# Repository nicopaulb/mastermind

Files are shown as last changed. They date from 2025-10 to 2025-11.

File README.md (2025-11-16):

# Electronic mastermind

Find the followings items : 
- `src` : Embedded code for the board
- `dts` : Project specific Zephyr bindings
- `boards`: Zephyr devicetree overlays for the nRF microcontrollers
- `7seg_driver_module`: Zephyr driver for 7-segments display with 74HC595 shift register
- `flutter-app` : Flutter companion application for interacting with the Mastermind via BLE
- `pcb` : All KiCad files for PCB manufacturing and electric schema

Youtube Video (https://www.youtube.com/watch?v=6QL7J55KHXo)

Read more about it here : https://blog.beniserv.fr/posts/mastermind/

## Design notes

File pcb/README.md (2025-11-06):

# KiCad PCB files

For Kicad 9

<p>
    
    
</p>

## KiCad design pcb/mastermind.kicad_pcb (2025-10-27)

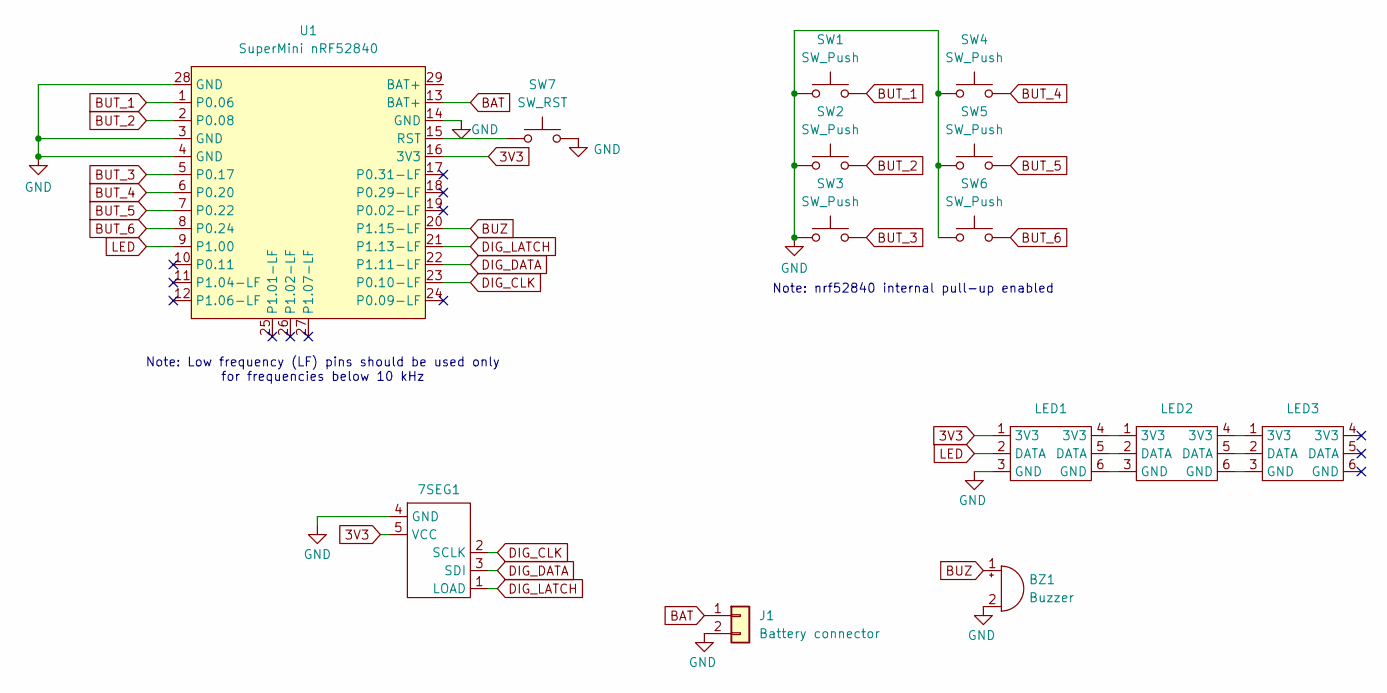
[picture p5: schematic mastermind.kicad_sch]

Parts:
7SEG1: 7seg
BZ1: Buzzer; Buzzer_12x9.5RM7.6
J1: Battery connector; JST_PH_B2B-PH-K_1x02_P2.00mm_Vertical
LED1: LED Strip 4 LED
LED2, LED3: LED Strip 2 LED
SW1, SW2, SW3, SW4, SW5, SW6: SW_Push; SW_PUSH-12mm
SW7: SW_RST; SW_PUSH-12mm
U1: SuperMini nRF52840; SuperMini NRF52840

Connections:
3V3: 7SEG1.5 (VCC), LED1.1 (3V3), U1.16 (3V3)
BAT: J1.1, U1.13 (BAT+)
BUT_1: SW1.2, U1.1 (P0.06)
BUT_2: SW2.2, U1.2 (P0.08)
BUT_3: SW3.2, U1.5 (P0.17)
BUT_4: SW4.2, U1.6 (P0.20)
BUT_5: SW5.2, U1.7 (P0.22)
BUT_6: SW6.2, U1.8 (P0.24)
BUZ: BZ1.1 (+), U1.20 (P1.15-LF)
DIG_CLK: 7SEG1.2 (SCLK), U1.23 (P0.10-LF)
DIG_DATA: 7SEG1.3 (SDI), U1.22 (P1.11-LF)
DIG_LATCH: 7SEG1.1 (LOAD), U1.21 (P1.13-LF)
GND: 7SEG1.4 (GND), BZ1.2 (-), J1.2, LED1.3 (GND), SW1.1, SW2.1, SW3.1, SW4.1, SW5.1, SW6.1, SW7.2, U1.3 (GND), U1.4 (GND), U1.14 (GND), U1.28 (GND)
LED: LED1.2 (DATA), U1.9 (P1.00)
unnamed: LED1.4 (3V3), LED2.1 (3V3)
unnamed: LED1.5 (DATA), LED2.2 (DATA)
unnamed: LED1.6 (GND), LED2.3 (GND)
unnamed: LED2.4 (3V3), LED3.1 (3V3)
unnamed: LED2.5 (DATA), LED3.2 (DATA)
unnamed: LED2.6 (GND), LED3.3 (GND)
unnamed: SW7.1, U1.15 (RST)

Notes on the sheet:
Note: nrf52840 internal pull-up enabled
Note: Low frequency (LF) pins should be used only for frequencies below 10 kHz

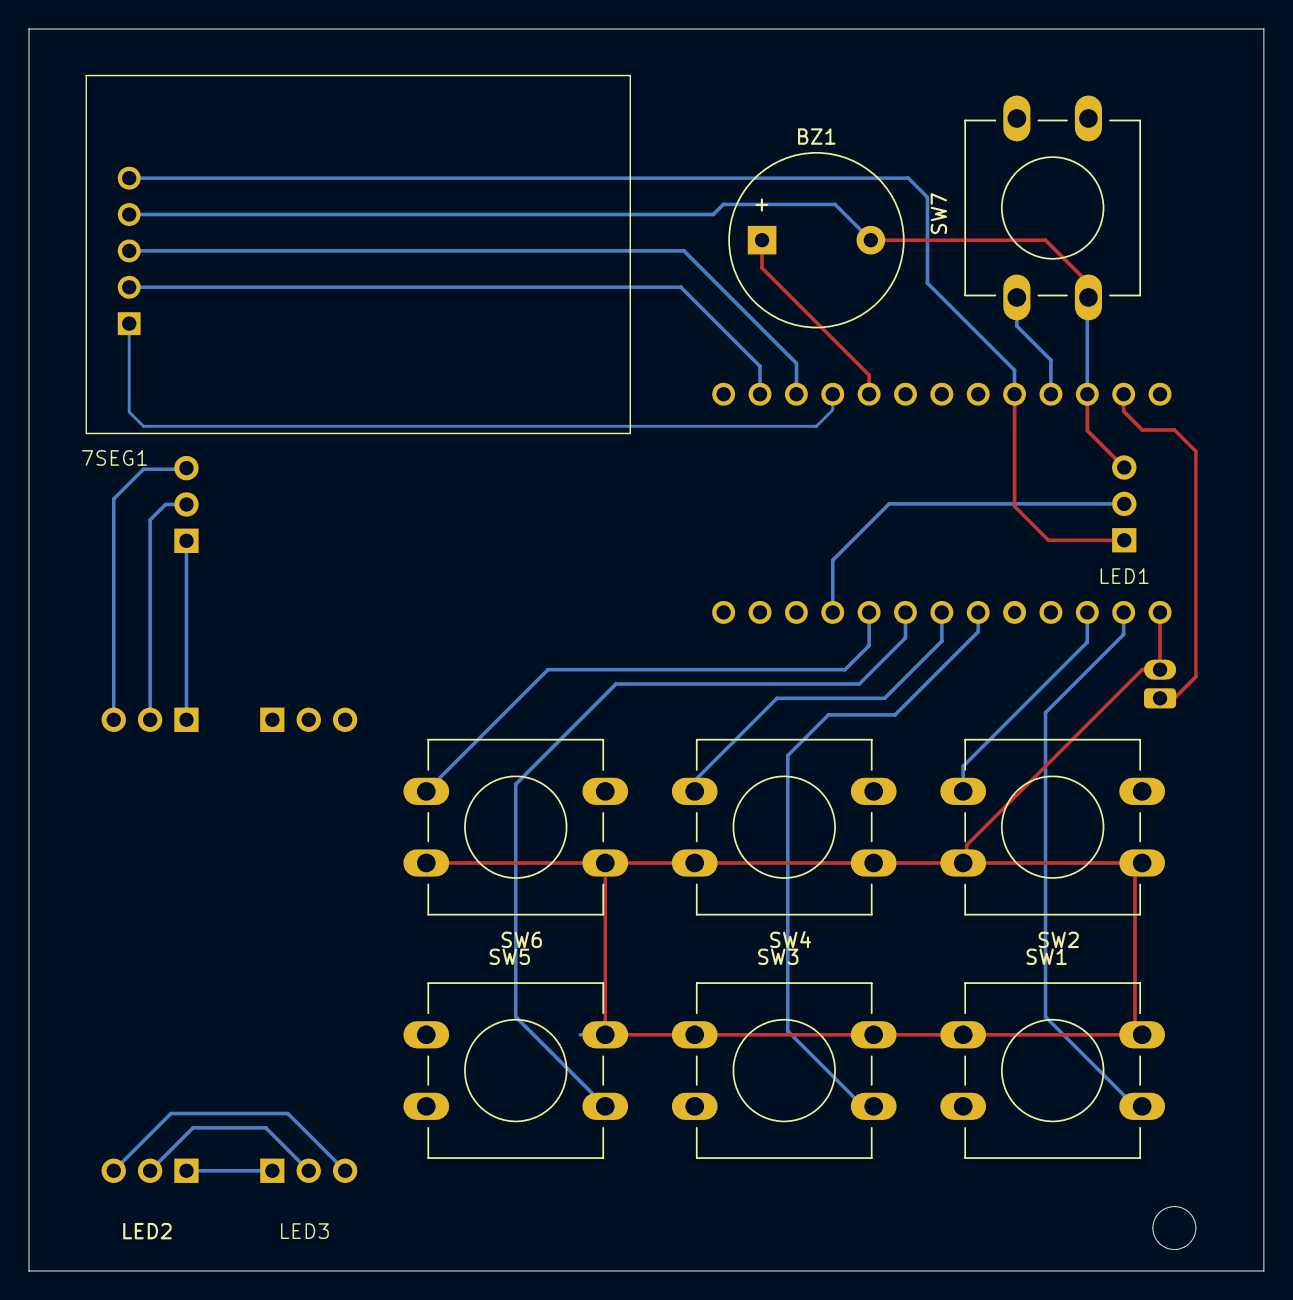
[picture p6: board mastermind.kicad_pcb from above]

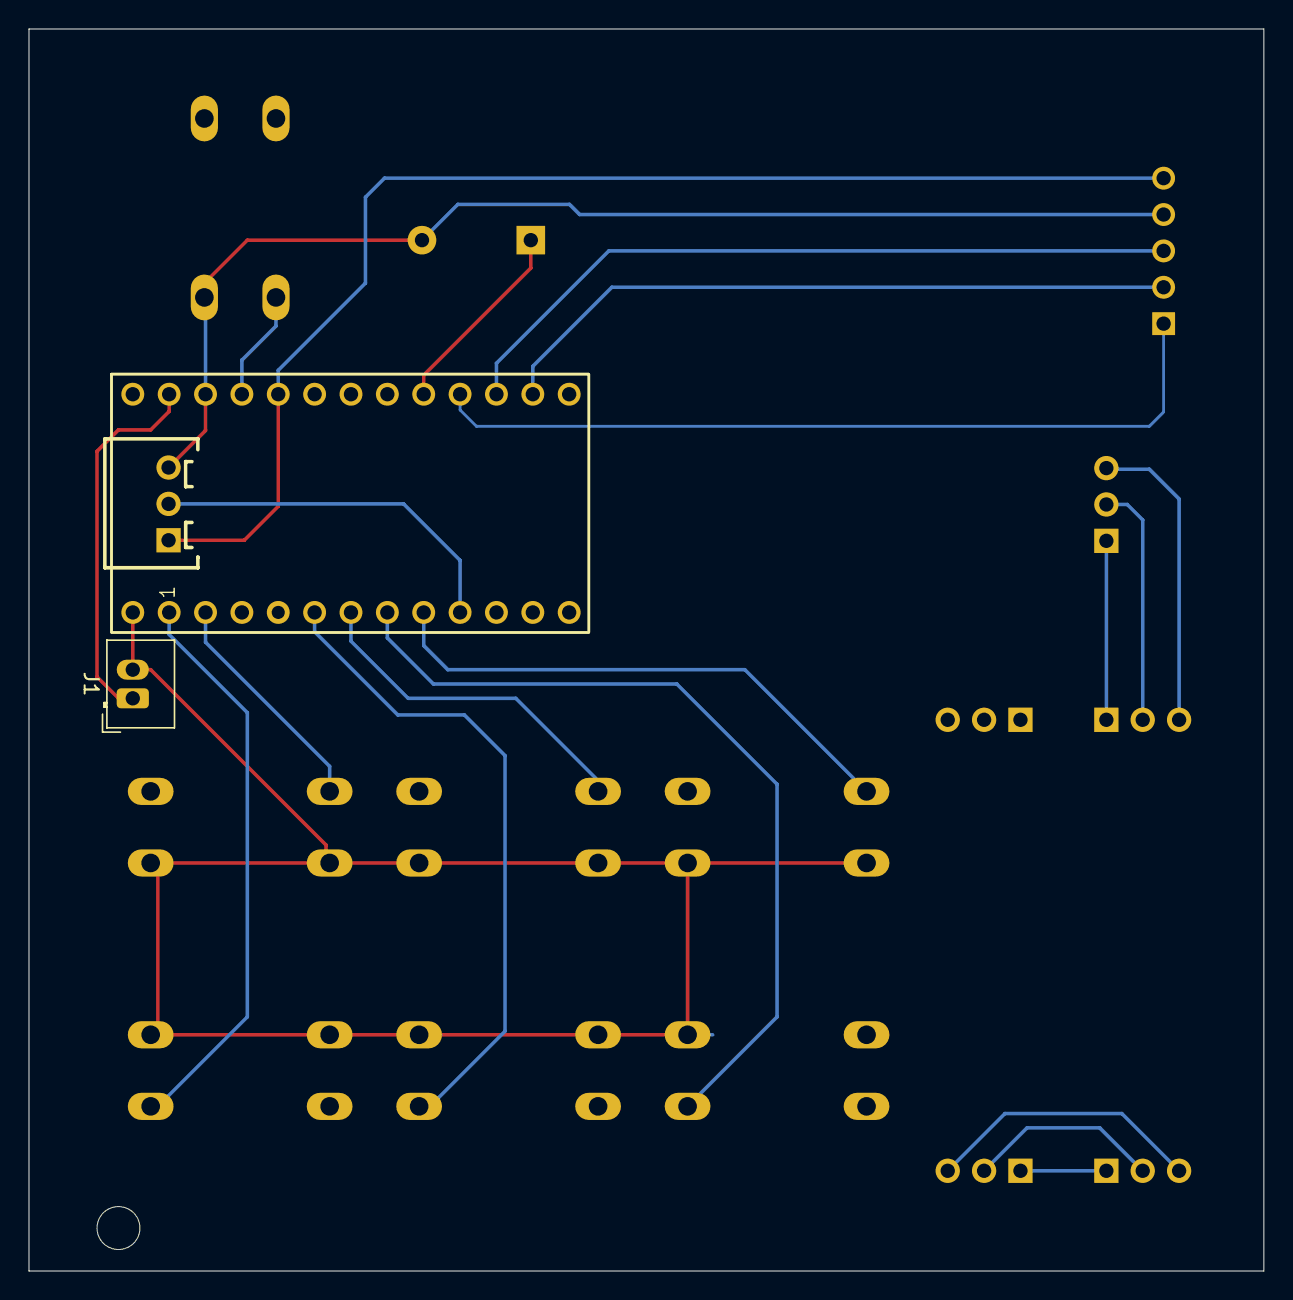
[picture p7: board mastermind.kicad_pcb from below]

Board: 2 copper layers, 86.2 x 86.8 mm, 14 parts (2 on the bottom side), 21 nets.

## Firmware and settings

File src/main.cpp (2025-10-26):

#include <zephyr/logging/log.h>
#include <zephyr/kernel.h>
#include <zephyr/device.h>
#include <zephyr/sys/util.h>
#include <zephyr/smf.h>
#include <zephyr/sys/poweroff.h>

#include "etl/array.h"
#include "combination.hpp"
#include "leds.hpp"
#include "buttons.hpp"
#include "ble.hpp"
#include "buzzer.hpp"
#include "display.hpp"
#include "app_cfg.hpp"

#define LOG_LEVEL 4

LOG_MODULE_REGISTER(main);

enum state
{
	STATE_START,
	STATE_CHECK_INPUT,
	STATE_CHECK_CMD,
	STATE_CLUES,
	STATE_END_WIN,
	STATE_END_LOST,
	STATE_OFF
};

static void state_start_run(void *o);
static void state_check_input_run(void *o);
static void state_check_cmd_run(void *o);
static void state_clues_run(void *o);
static void state_end_win_run(void *o);
static void state_end_lost_run(void *o);
static void state_off_run(void *o);

// FSM state variables
static led_strip leds;
static buzzer buzzer;
static display display;
static buttons buts;
static combination code;
static etl::array<combination, MAX_TRY> tentatives;
static uint8_t try_id;
static bool manual_mode;
static struct smf_ctx ctx;

static const struct smf_state states[] = {
	[STATE_START] = SMF_CREATE_STATE(NULL, state_start_run, NULL, NULL, NULL),
	[STATE_CHECK_INPUT] = SMF_CREATE_STATE(NULL, state_check_input_run, NULL, NULL, NULL),
	[STATE_CHECK_CMD] = SMF_CREATE_STATE(NULL, state_check_cmd_run, NULL, NULL, NULL),
	[STATE_CLUES] = SMF_CREATE_STATE(NULL, state_clues_run, NULL, NULL, NULL),
	[STATE_END_WIN] = SMF_CREATE_STATE(NULL, state_end_win_run, NULL, NULL, NULL),
	[STATE_END_LOST] = SMF_CREATE_STATE(NULL, state_end_lost_run, NULL, NULL, NULL),
	[STATE_OFF] = SMF_CREATE_STATE(NULL, state_off_run, NULL, NULL, NULL),
};

static void state_start_run(void *o)
{
	try_id = 0;
	tentatives[try_id].unset_all();
	leds.reset();

	if (!manual_mode)
	{
		// If manual mode is disabled, generate a random code
		code.random_fill();
	}

	display.show_number(1);
	buzzer.play_start();

	ble_update_status(tentatives, code, try_id);
	smf_set_state(&ctx, &states[STATE_CHECK_CMD]);
}

static void state_check_cmd_run(void *o)
{
	etl::bitset<BT_COMMAND_COUNT> &cmds = ble_get_commands();
	etl::array<uint8_t, BT_COMMAND_BUF_SIZE> &buf = ble_get_command_buf();
	const struct smf_state *next_state = &states[STATE_CHECK_INPUT];
	uint8_t pos = 0;

	while (cmds.any())
	{
		pos = cmds.find_first(true);
		switch (pos)
		{
		case BT_COMMAND_RESET:
			LOG_INF("Executing 'Reset' command");
			manual_mode = false;
			next_state = &states[STATE_START];
			break;
		case BT_COMMAND_OFF:
			LOG_INF("Executing 'Off' command");
			next_state = &states[STATE_OFF];
			break;
		case BT_COMMAND_CODE:
			LOG_INF("Executing 'Code' command");
			manual_mode = true;
			for (uint8_t i = 0; i < code.slots.size(); i++)
			{
				code.set_slot(i, static_cast<slot_value>(buf[i]));
			}
			next_state = &states[STATE_START];
			break;
		default:
			LOG_ERR("Unknown command");
			break;
		}
		cmds.set(pos, false);
	}

	smf_set_state(&ctx, next_state);
}

static void state_check_input_run(void *o)
{
	uint8_t slot_left = 0;
	button_val val = buts.wait_for_input(K_MSEC(1000));
	switch (val)
	{
	case button_val::BUTTON_VAL_1:
	case button_val::BUTTON_VAL_2:
	case button_val::BUTTON_VAL_3:
	case button_val::BUTTON_VAL_4:
	case button_val::BUTTON_VAL_5:
	case button_val::BUTTON_VAL_6:
		buzzer.play_button();
		slot_left = tentatives[try_id].set_slot_next(static_cast<slot_value>(val));
		break;
	case button_val::BUTTON_VAL_NONE:
		smf_set_state(&ctx, &states[STATE_CHECK_CMD]);
		return;
	default:
		LOG_ERR("Unknown button pressed");
		break;
	}

	if (slot_left == 0)
	{
		smf_set_state(&ctx, &states[STATE_CLUES]);
	}
	else
	{
		leds.update_combination(tentatives[try_id]);
		leds.refresh();
	}
}

static void state_clues_run(void *o)
{
	LOG_INF("[Combi %d] All slot filled, showing clues", try_id);
	bool guessed = tentatives[try_id].compute_clues(code);
	leds.update_combination(tentatives[try_id++]);
	leds.refresh();

	buzzer.play_clues();
	display.show_number(try_id + 1);

	ble_update_status(tentatives, code, try_id);

	if (guessed)
	{
		smf_set_state(&ctx, &states[STATE_END_WIN]);
	}
	else if (try_id >= tentatives.size())
	{
		smf_set_state(&ctx, &states[STATE_END_LOST]);
	}
	else
	{
		tentatives[try_id].unset_all();
		smf_set_state(&ctx, &states[STATE_CHECK_CMD]);
	}
}

static void state_end_win_run(void *o)
{
	LOG_INF("WIN !");
	buzzer.play_win();
	display.clear();

	// Wait a bit to show the win message
	k_sleep(K_SECONDS(5));
	manual_mode = false;
	smf_set_state(&ctx, &states[STATE_START]);
}

static void state_end_lost_run(void *o)
{
	LOG_INF("LOST !");
	buzzer.play_lose();
	display.clear();
	leds.update_combination(code);
	leds.refresh();

	// Wait a bit to show the lose message
	k_sleep(K_SECONDS(5));
	manual_mode = false;
	smf_set_state(&ctx, &states[STATE_START]);
}

static void state_off_run(void *o)
{
	LOG_INF("Powering off");
	leds.reset();
	sys_poweroff();
}

int main(void)
{
	if (!buts.init())
	{
		return 1;
	}

	if (!leds.init())
	{
		return 1;
	}

	if (!ble_init())
	{
		return 1;
	}

	if(!buzzer.init())
	{
		return 1;
	}

	if(!display.init())
	{
		return 1;
	}

	manual_mode = false;
	smf_set_initial(&ctx, &states[STATE_START]);

	while (1)
	{
		smf_run_state(&ctx);
	}

	return 1;
}

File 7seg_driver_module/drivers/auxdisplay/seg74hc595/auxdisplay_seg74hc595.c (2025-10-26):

/*
 * 74HC595 7-segment display driver
 * Copyright (c) 2025 Nicolas BESNARD
 * SPDX-License-Identifier: Apache-2.0
 */

#define DT_DRV_COMPAT zephyr_seg74hc595

#include <zephyr/kernel.h>
#include <zephyr/device.h>
#include <zephyr/drivers/gpio.h>
#include <zephyr/drivers/spi.h>
#include <zephyr/drivers/auxdisplay.h>
#include <string.h>
#include <zephyr/logging/log.h>
#include <zephyr/sys/util.h>

LOG_MODULE_REGISTER(seg74hc595_auxdisplay, CONFIG_AUXDISPLAY_LOG_LEVEL);

/* Segment bit definitions */
#define MINUS_BIT BIT(6) /* Segment G only */
#define DP_BIT BIT(7)    /* Decimal point */
#define BLANK (0)        /* No segments lit */

/* Segment mapping: A=bit0, B=bit1, C=bit2, D=bit3, E=bit4, F=bit5, G=bit6; DP=bit7 */
static const uint8_t digit_segment_codes[] = {
    0x3F, /* 0 */
    0x06, /* 1 */
    0x5B, /* 2 */
    0x4F, /* 3 */
    0x66, /* 4 */
    0x6D, /* 5 */
    0x7D, /* 6 */
    0x07, /* 7 */
    0x7F, /* 8 */
    0x6F, /* 9 */
};

#if DT_NUM_INST_STATUS_OKAY(DT_DRV_COMPAT) == 0
#warning "7 segments 74HC595 driver enabled without any devices"
#endif

struct seg74hc595_config
{
    struct spi_dt_spec spi;
    struct gpio_dt_spec latch_pin;
    bool common_anode;
    struct auxdisplay_capabilities capabilities;
};

struct seg74hc595_data
{
    uint8_t display_buf[4];
};

static int seg74hc595_update_display(const struct device *dev)
{
    const struct seg74hc595_config *cfg = dev->config;
    struct seg74hc595_data *data = dev->data;
    int rv = -1;

    struct spi_buf tx_spi_buf = {.buf = data->display_buf, .len = cfg->capabilities.columns};
    struct spi_buf_set tx_spi_buf_set = {.buffers = &tx_spi_buf, .count = 1};

    gpio_pin_set_dt(&cfg->latch_pin, 0);
    rv = spi_write_dt(&cfg->spi, &tx_spi_buf_set);
    if (rv)
    {
        LOG_ERR("spi_write_dt() failed, err %d", rv);
    }
    gpio_pin_set_dt(&cfg->latch_pin, 1);

    return rv;
}

static int seg74hc595_auxdisplay_write(const struct device *dev, const uint8_t *buf, uint16_t len)
{
    const struct seg74hc595_config *cfg = dev->config;
    struct seg74hc595_data *data = dev->data;
    uint32_t pos = len - 1;
    uint16_t i = 0;

    if (len > cfg->capabilities.columns)
    {
        return -EINVAL;
    }

    memset(data->display_buf, 0, sizeof(data->display_buf));

    while (i < len && pos >= 0)
    {
        char c = buf[i];
        uint8_t segment_code = 0;

        if (c >= '0' && c <= '9')
        {
            segment_code = digit_segment_codes[c - '0'];
        }
        else if (c == '-')
        {
            segment_code = MINUS_BIT;
        }
        else
        {
            segment_code = BLANK;
        }

        data->display_buf[pos] = cfg->common_anode ? ~segment_code : segment_code;

        /* Check if next character is a decimal point */
        if (i + 1 < len && buf[i + 1] == '.')
        {
            data->display_buf[pos] |= cfg->common_anode ? ~DP_BIT : DP_BIT; /* Add decimal point to current digit */
            i += 2;                                                         /* Skip both the character and the '.' */
        }
        else
        {
            i++;
        }
        pos--;
    }

    return seg74hc595_update_display(dev);
}

static int seg74hc595_auxdisplay_clear(const struct device *dev)
{
    const struct seg74hc595_config *cfg = dev->config;
    struct seg74hc595_data *data = dev->data;

    memset(data->display_buf, cfg->common_anode ? 0xFF : 0x00, sizeof(data->display_buf));

    return seg74hc595_update_display(dev);
}

static int seg74hc595_initialize(const struct device *dev)
{
    const struct seg74hc595_config *cfg = dev->config;

    if (cfg->capabilities.columns > 4 || !gpio_is_ready_dt(&cfg->latch_pin) || !spi_is_ready_dt(&cfg->spi))
    {
        return -ENODEV;
    }

    gpio_pin_configure_dt(&cfg->latch_pin, GPIO_OUTPUT_ACTIVE);

    return seg74hc595_auxdisplay_clear(dev);
}

static int seg74hc595_auxdisplay_display_on(const struct device *dev)
{
    return seg74hc595_update_display(dev);
}

static int seg74hc595_auxdisplay_display_off(const struct device *dev)
{
    uint8_t buffer_save[4];
    const uint8_t buffer_empty[4] = {0};
    struct seg74hc595_data *data = dev->data;
    int rv = -1;

    memcpy(buffer_save, data->display_buf, sizeof(data->display_buf));
    rv = seg74hc595_auxdisplay_write(dev, buffer_empty, sizeof(buffer_empty));
    memcpy(data->display_buf, buffer_save, sizeof(data->display_buf));
    return rv;
}

static int seg74hc595_auxdisplay_capabilities_get(const struct device *dev,
                                                  struct auxdisplay_capabilities *cap)
{
    const struct seg74hc595_config *cfg = dev->config;

    memcpy(cap, &cfg->capabilities, sizeof(*cap));
    return 0;
}

static const struct auxdisplay_driver_api seg74hc595_auxdisplay_api = {
    .write = seg74hc595_auxdisplay_write,
    .clear = seg74hc595_auxdisplay_clear,
    .display_on = seg74hc595_auxdisplay_display_on,
    .display_off = seg74hc595_auxdisplay_display_off,
    .capabilities_get = seg74hc595_auxdisplay_capabilities_get,
};

#define SEG74HC595_DEFINE(inst)                                                                                  \
    static const struct seg74hc595_config seg74hc595_config_##inst = {                                           \
        .spi = SPI_DT_SPEC_INST_GET(inst, SPI_WORD_SET(8) | SPI_TRANSFER_MSB, 0),                                \
        .latch_pin = GPIO_DT_SPEC_INST_GET(inst, latch_gpios),                                                   \
        .common_anode = DT_INST_PROP(inst, common_anode),                                                        \
        .capabilities =                                                                                          \
            {                                                                                                    \
                .columns = DT_INST_PROP(inst, digits),                                                           \
                .rows = 1,                                                                                       \
            },                                                                                                   \
    };                                                                                                           \
    static struct seg74hc595_data seg74hc595_data_##inst;                                                        \
    DEVICE_DT_INST_DEFINE(inst, seg74hc595_initialize, NULL, &seg74hc595_data_##inst, &seg74hc595_config_##inst, \
                          POST_KERNEL, CONFIG_AUXDISPLAY_INIT_PRIORITY,                                          \
                          &seg74hc595_auxdisplay_api);

DT_INST_FOREACH_STATUS_OKAY(SEG74HC595_DEFINE)

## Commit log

2025-09-30 Adapt sample
2025-10-07 Implement BLE command to device
2025-10-08 Fix all LEDs not being switched off
2025-10-09 flutter-app: filter mastermind device
2025-10-09 buzzer: add squeleton logic for new sound
    [buzzer.cpp, main.cpp]
2025-10-13 flutter-app: implement device screen
2025-10-13 buzzer: fix concurrent song not being played
    [buzzer.cpp, main.cpp]
2025-10-13 buzzer: add new sound effect
    [buzzer.cpp, main.cpp]
2025-10-13 buzzer: new starting sound
    [buzzer.cpp]
2025-10-13 buttons: debounce input
2025-10-26 promicro: create configuration for new board
2025-10-26 buttons: fix buttons on port 1
    [buttons.cpp]
2025-10-26 seg74hc595: add new custom driver
2025-10-26 seg74hc595: fix digits order
    [auxdisplay_seg74hc595.c]
2025-10-26 buzzer: remove buzzer prefix
    [buzzer.cpp]
2025-10-26 buttons: fix color order
2025-10-27 pcb: save kicad files
    [mastermind.kicad_pcb, mastermind.kicad_sch]
2025-10-27 pcb: update files
    [mastermind-B_Cu.gbl, mastermind-B_Mask.gbs, mastermind-B_Paste.gbp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]
2025-11-06 doc: update pcb readme
2025-11-08 leds: fill led array in correct order to match LED strips positions and directions
2025-11-08 pcb: update kicad files
